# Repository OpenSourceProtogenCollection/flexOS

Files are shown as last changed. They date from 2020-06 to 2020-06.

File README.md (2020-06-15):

# flexOS
 The full files created for Subwuffer the Protogen, to help anyone create their own protogen fursuit
 
 Please check the wiki to get started.
 
#### GitHub Info
 
 
 
 
#### Contact
 
 
 
 
 
#### Code Status
 
 
 
 
 Waiting on shipment of new microcontrollers to update shell and Python with static USB binds.

# Quick Build Video

Watch the video here (https://youtu.be/kCo-e5A9jBQ)

# Requirements
## Hardware
- WS2812B boards (or other FastLED-compatible LED matrices)
	- I recommend 8x8 grids for cheeks and shoulders, 16x16 grids for legs, and 8x32 grids (x2) for visors
	- These can be found cheaply on AliExpress, but you can buy the more power-efficient versions from Adafruit
- Power sources
	- You'll need to do your own calculations as to how much power you'll need. I ended up going with 4 NiMH AA batteries, which gives 4.8V for every 4-battery holder
- Arduino (or other avr microcontrollers)
	- I went with Nanos, but these may be a bit limited in memory, so I'd recommend ESP32s. This one is up to you. Again, cheap ones can be found on AliExpress	
- Raspberry Pi
	- This one is only if you want to switch emotes in real-time. You will need wireless and the extra GPIO, so get either a 3B+ or newer, or a 1B+ or a 2B+ with a wireless adapter. I went with a 2B+ with a wireless adapter. Don't get a Pi A or Pi B, there aren't enough GPIO pins.
- Hall-effect sensors or reed switches (only for emote switching)
- 220 Ohm resistors, wires etc

## Software
- Codepad of your choice (VSCode and N++ are my choice for these languages)
- Arduino IDE
	- You must also have the following libraries installed:
		- [https://github.com/FastLED/FastLED](FastLED) for drawing arrays of LEDs (can and should be installed from Library Manager)
		- [https://github.com/AaronLiddiment/LEDText](LEDText) for scrolling text
		- [https://github.com/AaronLiddiment/LEDMatrix](LEDMatrix) for drawing shapes. I actually recommend using [jorgen-vikinggod's fork](https://jorgen-vikinggod.github.io/LEDMatrix/) for added functionality.
	- If you're coding and flashing on the go, ArduinoDroid works quite well
- [https://pixilart.com/draw](PixilArt) (web app)
- An image overlay program. For Windows there's OVERLAY2, but it's pretty persistent nagware. There's a better program out there by the name of Image Overlay Utility, but I'm not going to link it here due to (potentially false) positive malware alerts on it. If you go Googling for this, I reiterate that I'm not liable for any damage done. With that said, it seems to work fine on my machine, I have not seen any suspicious activity. If you would like me to screenshot you overlays of your pixel art, shoot me a [Telegram message](https://t.me/JaredTamana).
- A Linux-flashed SD card for your Raspberry Pi. I recommend Raspberry Pi OS. For more details on software for your installation, check the wiki.

# Notes
- I do not support macOS or Linux at this time. The reason I don't support macOS is because I don't own a macOS machine. However, the reason I don't support Linux is because the IDE SUCKS on Linux. There's no Library Manager, the Import Libraries tool is broken, your headers and libraries can't just be in the same folder as your sketch, the auto-format tool behaves strangely, shift-backspace is a nightmare... I could go on, but in short, just don't code Arduino on Linux. It hurts me to not support this because I love Linux and it sucks to have to switch between my Windows machine and my RPi constantly, but until Arduino fixes their IDE, I can't use it. If there's something specific that needs to be fixed for Linux or macOS compatibility let me know and I can look into fixing it.
- This is a WORK IN PROGRESS. I'm very much learning and working with this.
- These are Subwuffer's files in their entirety. You are welcome to use them as-is, but I highly encourage diving into the code and customizing things. I've made it very easy through code comments and the wiki to find your way around ^^
- I do not own the protogen species. For more info on the species and what can and cannot be used in your protogen, please visit [the creator's website](https://www.primaproto.com/). At the time of writing, this site is down for maintenance, but a [backup](https://web.archive.org/web/20191025141630/https://www.primaproto.com/) can be found on the Wayback Machine. For some reason this backup is SUPER slow, so the most relevant documentation has also been saved [in PDF format](https://drive.google.com/drive/folders/186GqGnEvYNcJsp2UskimsFtEwQ23Y9nJ?usp=sharing). (These are © MaliceRisu and therefore are not part of OSPC, they're only linked here for your convienence.)
- Big thanks to [Jting-F](https://www.youtube.com/channel/UCz8RfRGTDPPoexpyAg22kbg) for the inspiration and guidance along the way <3
- Like what I do? You can find a Sponsor button right beside the Watch, Star and Fork buttons. Any bit is really appreciated. I put a lot of time into this project because I saw a need for it and I enjoy it, but it's completely free for anyone to use.

# Getting in touch
I love to see what others make! If you have any questions or just want to chat about this project, you can click one of the badges above to get in touch with me. Please do try to contact me on Telegram first, that's where I'm most active.

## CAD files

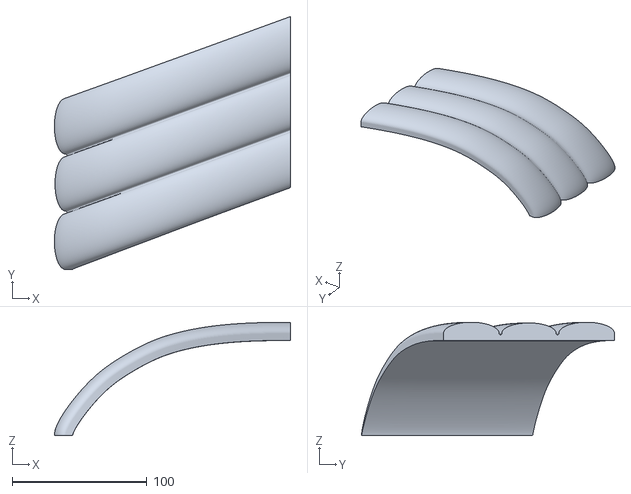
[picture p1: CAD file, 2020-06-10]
modeling/chest plate left completed_2.stl
175.4 x 187.8 x 84.2

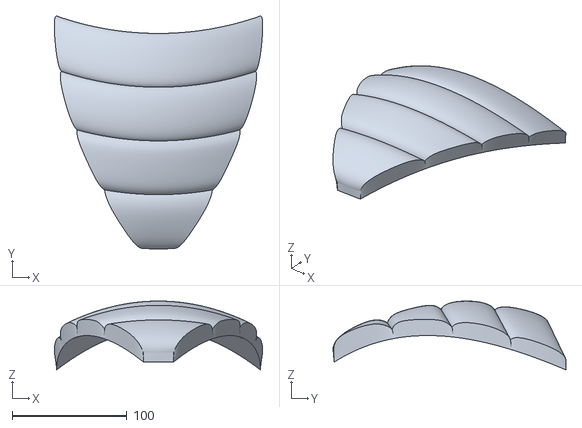
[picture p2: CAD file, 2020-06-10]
modeling/crotch plate completed_1.stl
181.9 x 203.3 x 60.1

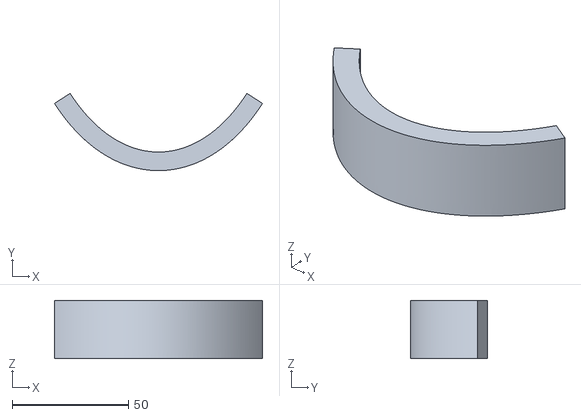
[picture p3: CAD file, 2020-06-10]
modeling/crotch plate connector completed_1.stl
89.5 x 33.2 x 25.0

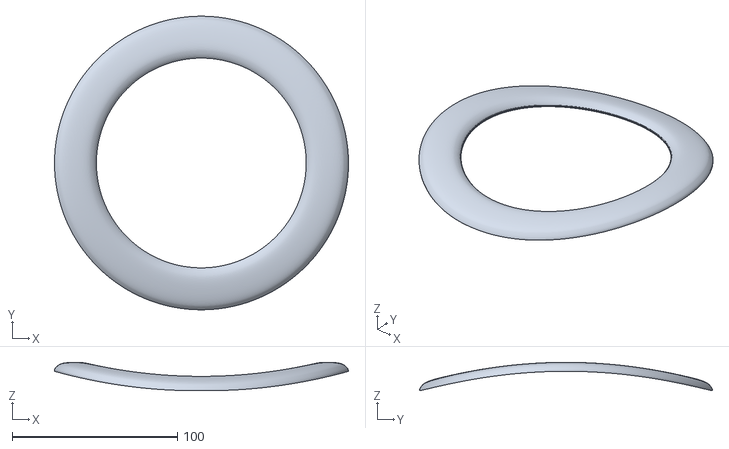
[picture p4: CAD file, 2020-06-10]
modeling/shoulder palte completed_2.stl
178.0 x 177.8 x 17.2

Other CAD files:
modeling/chest plate right completed_2.stl

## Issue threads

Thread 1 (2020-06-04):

ProtogenSSH: Buttons do not save to Internal Storage

JaredTheWolf, 2020-06-04:

JaredTheWolf, 2020-06-04:
I'm not sure how I want to implement this right now.

- I could use an SQLite database for it
- I could use a JSON (or other file) to store each button as its own Object

JaredTheWolf, 2020-06-04:
As of the latest commit (50ca525f391bec891c94252341ccfebedc6a58a6) read/write has been implemented but write don't seem to be working properly as read always reports the file as not found. Investigating.

JaredTheWolf, 2020-06-04:
Fixed by 5d37c59254449ff868785f9808e9db44832bd5c0

Closed 2020-06-04.

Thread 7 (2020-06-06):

ProtogenSSH: Passwords are not stored in encrypted SharedPrefs

JaredTheWolf, 2020-06-06:
Due to some issues with the crypto classes, passwords are currently stored alongside username and port info in regular SharedPrefs. This should probably be corrected. When I close this issue, I'll likely maintain a version of ProtogenSSH that does not use the crypto, as the current SDK I'm building for does not support it, but I want people to be able to use old phones they have knocking around if they choose to do so.

Closed 2020-06-07.

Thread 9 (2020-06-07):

Shell: Create a script with udev rules that statically binds USB devices

JaredTheWolf, 2020-06-07:
https://unix.stackexchange.com/questions/66901/how-to-bind-usb-device-under-a-static-name

JaredTheWolf, 2020-06-27:
I've received some ESP32s, so this will be worked on in the coming days.

JaredTheWolf, 2022-01-01:
This was never worked on due to incompatibilites between ESP32 and the FastLED library. I am reinvesting in this project and will attempt to debug these incompatibilities and report them to the library maintainers accordingly, however there is no guarantee that it will work (if it's a problem with me) or that the maintainers will help (if it's FastLED).

This issue technically does not need to be done with ESP32s, I can work it out with Arduino Nanos, but I'd like to sort out my MCs first due to the memory limitations we were seeing on 328 Nanos.

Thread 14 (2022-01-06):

[Arduino] 16x16 Incomplete

JaredTheWolf, 2022-01-06:
**Issue Location**
Arduino example sketch `arduino16x16.ino`

**Describe the issue**
- Out of date in-code docs on line 63
- No implementation of serial connection to Pi
- Needs further testing to ensure working pattern drawing (16x16 was never as well tested as 32x8)

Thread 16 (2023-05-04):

[FEAT] ESP Based Web Interface

GetLifty, 2023-05-04:
**Is your feature request related to a problem? Please describe.**
The current system for controlling which animation is occuring on the panel requires the user to SSH into a raspberry pi and use python scripts to send serial commands to the microcontroller. This requires a base technical knowledge and is unwieldy for less experienced users.

**Describe the solution you'd like**
A simpler and cheaper system could be implemented using a simple ESP based web server that takes user input and sends commands across a serial link. This could also allow for the implementation of effects such as voice control using an I2S mic at a lower cost than the Pi alternative. It would still have the benefit of acting as an AP but requires significantly less time to prepare as no bash scripts have to be run for setup.

**Describe alternatives you've considered**
A Pi Zero W based alternative could also achieve cost savings, but would still use more power and would not be as readily purchasable as ESP chips.

**Additional context**
I have begun working on an implementation of this in the time whilst I wait for other components to arrive and have succesfully gotten a working AP, webpage and serial output working. I would be happy to commit this code if this sounds like a feature that could be implemented :). See attached screenshots for my progress!
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

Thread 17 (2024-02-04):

Work with Raspberry Pi 3 Model B V1.2

Maxime66410, 2024-02-04:
Hello, Do you think it works with a Raspberry Pi 3 Model B V1.2 ?

https://fccid.io/2ABCB-RPI32

https://techinfodepot.shoutwiki.com/wiki/RPF_Raspberry_Pi_3_Model_B

https://fcc.report/FCC-ID/2ABCB-RPI32

https://www.amazon.fr/Raspberry-Pi-Carte-Mère-Model/dp/B01CD5VC92

Maxime66410, 2024-02-05:
Raspberry Pi 3 B+ -> [Extended 40-pin GPIO header](https://www.raspberrypi.com/products/raspberry-pi-3-model-b-plus/)
Raspberry Pi 3 Model B -> [Extended 40-pin GPIO header](https://www.raspberrypi.com/products/raspberry-pi-3-model-b/)

I think that should do it !

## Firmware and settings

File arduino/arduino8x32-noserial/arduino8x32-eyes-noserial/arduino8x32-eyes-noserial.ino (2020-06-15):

/*
    This file is part of flexOS and The Open Source Protogen Collection (OSPC).
    flexOS is free software under the MIT license. Please see https://opensource.org/licenses/MIT for more info
*/

/*                 _       _
     /\           | |     (_)
    /  \   _ __ __| |_   _ _ _ __ ______ _____      _____
   / /\ \ | '__/ _` | | | | | '_ \______/ _ \ \ /\ / / _ \
  / ____ \| | | (_| | |_| | | | | |    | (_) \ V  V / (_) |
 /_/    \_\_|  \__,_|\__,_|_|_| |_|     \___/ \_/\_/ \___/ */

#include "config.h" // this file includes our libraries and device-specific variables
#include "declarations.h" // this file includes variables for LED patterns

// creating the matrix using LEDMatrix
// note that height and width are flipped in this example due to TILE_TYPE
cLEDMatrix <MATRIX_TILE_HEIGHT, MATRIX_TILE_WIDTH, MATRIX_TILE_TYPE> ledmatrix;
// creating a pointer to the matrix so FastLED can still operate
CRGB *leds = ledmatrix[0];
// declaring LEDText
cLEDText ScrollingMsg;

// Purpose: Draws a single LED, then delays. Good for particle effects.
// Accepts: int index of LED, long int hex code, int time to delay after drawing (optional)
// Returns: Nothing
void singleLED(int number, long int colour, int delaytime = 0) {
  leds[number] = colour;
  if (delaytime > 0) {
    FastLED.show();
    FastLED.delay(delaytime);
  }
}

// Purpose: Draws LEDs by running through the pixels, one by one, and seeing if they should be lit up according to their array
// Accepts: uint16_t[] of your desired pattern, int size of the pattern array, long int hex code
// Returns: nothing
// For more details on how this works, see https://github.com/OpenSourceProtogenCollection/flexOS/wiki/Notes:-PROGMEM
void drawPattern(uint16_t patternArray[], int patternSize, long int colour) {
  // PGM comes into play here. For more info about PGM, see the declarations header or the wiki
  uint16_t nextPixel; // holds current RAM value from PGM
  int pixelCounter = 0; // increments when a pixel is placed
  for (int i = 0; i < NUM_LEDS; i++) { // loop through LED in the matrix
    for (int j = 0; j < patternSize; j++) { // check every element in the pattern array for the current LED
      nextPixel = pgm_read_word(&patternArray[pixelCounter]); // pull element into RAM
      if (i == nextPixel) { // if the pixel in the matrix matches the array element
        leds[i] = colour; // turn the pixel the specified colour
        pixelCounter++; // move to the next pixel
      }
    }
  }
}

// pattern-writing functions start here

void writeAttnEyes() {
  FastLED.clear();
  drawPattern(attentionEyes, ATTN_EYES, CRGB::Red);
  FastLED.show();
  FastLED.delay(500);
  FastLED.clear();
  FastLED.show();
  FastLED.delay(500);
}

void writeChgEyes() {
  FastLED.clear();
  drawPattern(chargeEyes, CHG_EYES, CRGB::Yellow);
  FastLED.show();
  FastLED.delay(500);
  for (int i = 0; i < 2; i++) {
    drawPattern(chargeEyesRemove, CHG_EYES_R, CRGB::Black);
    drawPattern(chargeEyesAdd, CHG_EYES_R, CRGB::Yellow);
    FastLED.show();
    FastLED.delay(500)
    FastLED.clear();
    drawPattern(chargeEyes, CHG_EYES, CRGB::Yellow);
    FastLED.show();
    FastLED.delay(500)
  }
    singleLED(12, CRGB::Yellow, 100);
    singleLED(62, CRGB::Yellow, 100);
    singleLED(88, CRGB::Yellow, 100);
    singleLED(161, CRGB::Yellow, 100);
    singleLED(234, CRGB::Yellow, 100);
    singleLED(167, CRGB::Yellow, 500);
    FastLED.clear();
}

void writeCoffeeEyes() {
    FastLED.clear();
    drawPattern(coffeeEyesBlue, COF_EYES_B, purpleblue);
    drawPattern(coffeeEyesWhite, COF_EYES_W, CRGB::White);
    FastLED.show(); FastLED.delay(750);
    drawPattern(coffeeEyesRemove, COF_EYES_R, CRGB::Black);
    drawPattern(coffeeEyesAdd, COF_EYES_R, CRGB::White);
    FastLED.show();
    FastLED.delay(500);
}

void writeDniEyes() {
    FastLED.clear();
    drawPattern(dniEyes, DNI_EYES, CRGB::Red);
    FastLED.show();
    FastLED.delay(1000);
    drawPattern(dniEyes, DNI_EYES, CRGB::White);
    FastLED.show();
    delay (1000);
}

void writeError() {
  while (true) {
    FastLED.clear();
    drawPattern(errSt, ERR_S, CRGB::Red);
    FastLED.show();
    FastLED.delay(1000);
    drawPattern(errR1, ERR_1, CRGB::Black);
    drawPattern(errA, ERR_1, CRGB::Red);
    FastLED.show();
    FastLED.delay(250);
    FastLED.clear();
    drawPattern(errSt, ERR_S, CRGB::Red);
    FastLED.show();
    FastLED.delay(250);
    drawPattern(errR1, ERR_1, CRGB::Black);
    drawPattern(errA, ERR_1, CRGB::Red);
    drawPattern(errAGn, ERR_2, seafoam);
    drawPattern(errAB, ERR_2, CRGB::Blue);
    FastLED.show();
    FastLED.delay(100);
    FastLED.clear();
    drawPattern(errSt, ERR_S, CRGB::Red);
    drawPattern(errAGn, ERR_2, seafoam);
    drawPattern(errAB, ERR_2, CRGB::Blue);
    drawPattern(errAY, ERR_Y, CRGB::Yellow);
    drawPattern(errAGr, ERR_3, bluegray);
    drawPattern(errAP, ERR_3, CRGB::Purple);
    FastLED.show();
    FastLED.delay(250);
    drawPattern(errR2, ERR_2, CRGB::Black);
    FastLED.show();
    FastLED.delay(250);
}

void writeCheckEyes() {
    FastLED.clear();
    drawPattern(checkEyes1, CHK_EYES_1, CRGB::Green);
    FastLED.show();
    FastLED.delay(250);
    drawPattern(checkEyes2, CHK_EYES_M, CRGB::Green);
    FastLED.show();
    FastLED.delay(250);
    drawPattern(checkEyes3, CHK_EYES_M, CRGB::Green);
    FastLED.show();
    FastLED.delay(250);
    drawPattern(checkEyes4, CHK_EYES_L, CRGB::Green);
    FastLED.show();
    FastLED.delay(1000);
}

void writeWrongEyes() {
    FastLED.clear();
    ledmatrix.DrawLine(13, 7, 20, 0, CRGB::Red);
    ledmatrix.DrawLine(13, 0, 15, 2, CRGB::Red);
    ledmatrix.DrawLine(20, 7, 18, 5, CRGB::Red);
    FastLED.show();
    FastLED.delay(150);
    FastLED.clear();
    FastLED.show();
    FastLED.delay(150);
    ledmatrix.DrawLine(13, 7, 20, 0, CRGB::Red);
    ledmatrix.DrawLine(13, 0, 15, 2, CRGB::Red);
    ledmatrix.DrawLine(20, 7, 18, 5, CRGB::Red);
    FastLED.show();
    FastLED.delay(150);
    FastLED.clear();
    FastLED.show();
    FastLED.delay(150);
    ledmatrix.DrawLine(13, 7, 20, 0, CRGB::Red);
    ledmatrix.DrawLine(13, 0, 15, 2, CRGB::Red);
    ledmatrix.DrawLine(20, 7, 18, 5, CRGB::Red);
    FastLED.show();
    FastLED.delay(1000);
}

void writeIdleEyes() {
    FastLED.clear();
    ledmatrix.DrawRectangle(3, 4, 4, 6, CRGB::White);
    ledmatrix.DrawRectangle(27, 4, 28, 6, CRGB::White);
    FastLED.show();
    FastLED.delay(3000);
    FastLED.clear();
    ledmatrix.DrawRectangle(3, 4, 4, 5, CRGB::White);
    ledmatrix.DrawRectangle(27, 4, 28, 5, CRGB::White);
    FastLED.show();
    delay(100);
    FastLED.clear();
    ledmatrix.DrawRectangle(3, 4, 4, 4, CRGB::White);
    ledmatrix.DrawRectangle(27, 4, 28, 4, CRGB::White);
    FastLED.show();
    delay(100);
    FastLED.clear();
    ledmatrix.DrawRectangle(3, 4, 4, 5, CRGB::White);
    ledmatrix.DrawRectangle(27, 4, 28, 5, CRGB::White);
    FastLED.show();
    delay(100);
}

void writeCryingEyes() {
  // this will probably just be shorter if I write it with int arrays
  while (true) {
    FastLED.clear();
    ledmatrix.DrawRectangle(3, 4, 4, 5, CRGB::White);
    ledmatrix.DrawRectangle(27, 4, 28, 5, CRGB::White);
    FastLED.show();
    FastLED.delay(1000);
    ledmatrix.DrawLine(3, 3, 4, 3, CRGB::Blue);
    ledmatrix.DrawLine(27, 3, 28, 3, CRGB::Blue);
    FastLED.show();
    delay(200);
    FastLED.clear();
    ledmatrix.DrawRectangle(3, 4, 4, 5, CRGB::White);
    ledmatrix.DrawRectangle(27, 4, 28, 5, CRGB::White);
    ledmatrix.DrawLine(3, 2, 4, 2, CRGB::Blue);
    ledmatrix.DrawLine(27, 2, 28, 2, CRGB::Blue);
    FastLED.show();
    delay(200);
    FastLED.clear();
    ledmatrix.DrawRectangle(3, 4, 4, 5, CRGB::White);
    ledmatrix.DrawRectangle(27, 4, 28, 5, CRGB::White);
    ledmatrix.DrawLine(3, 3, 4, 3, CRGB::Blue);
    ledmatrix.DrawLine(27, 3, 28, 3, CRGB::Blue);
    ledmatrix.DrawLine(3, 1, 4, 1, CRGB::Blue);
    ledmatrix.DrawLine(27, 1, 28, 1, CRGB::Blue);
    FastLED.show();
    delay(200);
    FastLED.clear();
    ledmatrix.DrawRectangle(3, 4, 4, 5, CRGB::White);
    ledmatrix.DrawRectangle(27, 4, 28, 5, CRGB::White);
    ledmatrix.DrawLine(3, 2, 4, 2, CRGB::Blue);
    ledmatrix.DrawLine(27, 2, 28, 2, CRGB::Blue);
    ledmatrix.DrawLine(3, 0, 4, 0, CRGB::Blue);
    ledmatrix.DrawLine(27, 0, 28, 0, CRGB::Blue);
    FastLED.show();
    delay(200);
    FastLED.clear();
    ledmatrix.DrawRectangle(3, 4, 4, 5, CRGB::White);
    ledmatrix.DrawRectangle(27, 4, 28, 5, CRGB::White);
    ledmatrix.DrawLine(3, 1, 4, 1, CRGB::Blue);
    ledmatrix.DrawLine(27, 1, 28, 1, CRGB::Blue);
    FastLED.show();
    delay(200);
    FastLED.clear();
    ledmatrix.DrawRectangle(3, 4, 4, 5, CRGB::White);
    ledmatrix.DrawRectangle(27, 4, 28, 5, CRGB::White);
    ledmatrix.DrawLine(3, 0, 4, 0, CRGB::Blue);
    ledmatrix.DrawLine(27, 0, 28, 0, CRGB::Blue);
    FastLED.show();
    delay(200);
  }
}

void writeIdEyes() {
  while (true) {
    FastLED.clear();
    ledmatrix.DrawRectangle(6, 0, 25, 7, CRGB::Blue);
    ledmatrix.DrawLine(19, 3, 15, 3, CRGB::Blue);
    ledmatrix.DrawLine(15, 5, 23, 5, CRGB::Blue);
    ledmatrix.DrawRectangle(9, 4, 10, 5, CRGB::Blue);
    ledmatrix.DrawRectangle(8, 1, 11, 2, CRGB::Blue);
    FastLED.show(); FastLED.delay(500);
    FastLED.clear();
    FastLED.show();
    FastLED.delay(750);
  }
}

void writeJoyEyes(bool laughing) {
  int eyeSpeed1;
  int eyeSpeed2;

  if (laughing) {
    eyeSpeed1 = 200;
    eyeSpeed2 = 150;
  }
  else {
    eyeSpeed1 = 1000;
    eyeSpeed2 = 1000;
  }
  
    FastLED.clear();
    ledmatrix.DrawLine(3, 4, 5, 6, 0xFFFFFF);
    ledmatrix.DrawLine(7, 4, 6, 5, 0xFFFFFF);
    ledmatrix.DrawLine(24, 4, 26, 6, 0xFFFFFF);
    ledmatrix.DrawLine(28, 4, 27, 5, 0xFFFFFF);
    FastLED.show();
    FastLED.delay(eyeSpeed1);
    FastLED.clear();
    ledmatrix.DrawLine(3, 5, 5, 7, 0xFFFFFF);
    ledmatrix.DrawLine(7, 5, 6, 6, 0xFFFFFF);
    ledmatrix.DrawLine(24, 5, 26, 7, 0xFFFFFF);
    ledmatrix.DrawLine(28, 5, 27, 6, 0xFFFFFF);
    FastLED.show();
    FastLED.delay(eyeSpeed2);
  }
}

void writePhoneEyes() {
    FastLED.clear();
    ledmatrix.DrawFilledRectangle(8, 1, 11, 3, CRGB::Blue);
    ledmatrix.DrawFilledRectangle(20, 1, 23, 3, CRGB::Blue);
    ledmatrix.DrawFilledRectangle(21, 3, 10, 5, CRGB::Blue);
    leds[180] = CRGB::Blue;
    leds[75] = CRGB::Blue;
    FastLED.show();
    delay(250);
    leds[51] = CRGB::Green;
    leds[52] = CRGB::Green;
    leds[58] = CRGB::Green;
    leds[70] = CRGB::Green;
    leds[73] = CRGB::Green;
    leds[182] = CRGB::Green;
    leds[185] = CRGB::Green;
    leds[197] = CRGB::Green;
    leds[203] = CRGB::Green;
    leds[204] = CRGB::Green;
    FastLED.show();
    delay(250);
    ledmatrix.DrawLine(26, 5, 26, 6, CRGB::Green);
    ledmatrix.DrawLine(25, 7, 24, 7, CRGB::Green);
    ledmatrix.DrawLine(6, 7, 7, 7, CRGB::Green);
    ledmatrix.DrawLine(5, 6, 5, 5, CRGB::Green);
    FastLED.show();
    delay(250);
  }
}

void writeSleepyEyes() {
  while (true) {
    FastLED.clear();
    ledmatrix.DrawLine(28, 5, 25, 5, CRGB::White);
    ledmatrix.DrawLine(6, 5, 3, 5, CRGB::White);
    FastLED.show();
    FastLED.delay(1000);
    FastLED.clear();
    drawPattern(zzzEyes1, ZZZ_EYES_S, CRGB::White);
    FastLED.show();
    FastLED.delay(300);
    drawPattern(zzzEyesA1, ZZZ_EYES_M, CRGB::White);
    drawPattern(zzzEyesR1, ZZZ_EYES_M, CRGB::Black);
    FastLED.show();
    FastLED.delay(300);
    FastLED.clear();
    drawPattern(zzzEyes1, ZZZ_EYES_S, CRGB::White);
    drawPattern(zzzEyesA2, ZZZ_EYES_M, CRGB::White);
    drawPattern(zzzEyesR2, ZZZ_EYES_M, CRGB::Black);
    FastLED.show();
    FastLED.delay(300);
    FastLED.clear();
    drawPattern(zzzEyes1, ZZZ_EYES_S, CRGB::White);
    drawPattern(zzzEyesA3, ZZZ_EYES_M, CRGB::White);
    drawPattern(zzzEyesR3, ZZZ_EYES_M, CRGB::Black);
    FastLED.show();
    if (Serial.available() > 0)
      break;
    FastLED.delay(300);
    FastLED.clear();
    drawPattern(zzzEyes1, ZZZ_EYES_S, CRGB::White);
    FastLED.show();
    FastLED.delay(1000);
  }
}

void writeLoadingEyes() {
  /* loading eyes - currently broken due to RAM usage */
    FastLED.clear();
    singleLED(151, rainbow[0]);
    singleLED(150, rainbow[1]);
    singleLED(149, rainbow[2]);
    singleLED(148, rainbow[3]);
    singleLED(147, rainbow[4]);
    singleLED(146, rainbow[5]);
    singleLED(145, rainbow[6]);

    // horrid manual method of doing things
    //    ledmatrix.ShiftUp();
    //    singleLED(topRow[0], rainbow[0], 150);
    //    ledmatrix.ShiftUp();
    //    singleLED(topRow[1], rainbow[0]);
    //    singleLED(topRow[0], rainbow[1], 150);
    //    ledmatrix.ShiftUp();
    //    singleLED(topRow[2], rainbow[0]);
    //    singleLED(topRow[1], rainbow[1]);
    //    singleLED(topRow[0], rainbow[2], 150);
    //    ledmatrix.ShiftUp();
    //    singleLED(topRow[3], rainbow[0]);
    //    singleLED(topRow[2], rainbow[1]);
    //    singleLED(topRow[1], rainbow[2]);
    //    singleLED(topRow[0], rainbow[3], 150);
    //    ledmatrix.ShiftUp();
    //    singleLED(topRow[4], rainbow[0]);
    //    singleLED(topRow[3], rainbow[1]);
    //    singleLED(topRow[2], rainbow[2]);
    //    singleLED(topRow[1], rainbow[3]);
    //    singleLED(topRow[0], rainbow[4], 150);
    //    ledmatrix.ShiftUp();
    //    singleLED(topRow[5], rainbow[0]);
    //    singleLED(topRow[4], rainbow[1]);
    //    singleLED(topRow[3], rainbow[2]);
    //    singleLED(topRow[2], rainbow[3]);
    //    singleLED(topRow[1], rainbow[4]);
    //    singleLED(topRow[0], rainbow[5], 150);
    //    ledmatrix.ShiftUp();
    //    singleLED(topRow[6], rainbow[0]);
    //    singleLED(topRow[5], rainbow[1]);
    //    singleLED(topRow[4], rainbow[2]);
    //    singleLED(topRow[3], rainbow[3]);
    //    singleLED(topRow[2], rainbow[4]);
    //    singleLED(topRow[1], rainbow[5]);
    //    singleLED(topRow[0], rainbow[6], 500);
    //    ledmatrix.ShiftRight();
    //    FastLED.show();

    // this is functional, but ShiftLeft and ShiftRight stall due to a lack of RAM. I'll have to rewrite it for manual shifting.
    for (int i = 0; i < 26; i++) {
      for (int j = 0; j <= i; j++) {
        singleLED(sequence[i - j], rainbow[j]);
      }
      FastLED.show();
      FastLED.delay(1000);
  }
}

void writeLostHandlerEyes() {
    ledmatrix.DrawFilledRectangle(0, 0, 31, 7, CRGB::White);

    if (ScrollingMsg.UpdateText() == -1)
      ScrollingMsg.SetText((unsigned char *)handlerEyesText, sizeof(handlerEyesText) - 1);
    else
      FastLED.show();
    FastLED.delay(15);
  }
}

void writeLowBatteryEyes() {
  while (true) {
    FastLED.clear();
    ledmatrix.DrawRectangle(8, 0, 9, 6, CRGB::White);
    ledmatrix.DrawRectangle(10, 0, 11, 2, CRGB::White);
    ledmatrix.DrawRectangle(13, 0, 17, 6, CRGB::White);
    ledmatrix.DrawLine(14, 1, 14, 5, CRGB::White);
    ledmatrix.DrawLine(19, 6, 19, 2, CRGB::White);
    ledmatrix.DrawLine(20, 0, 20, 1, CRGB::White);
    ledmatrix.DrawLine(21, 2, 21, 3, CRGB::White);
    ledmatrix.DrawLine(22, 0, 22, 1, CRGB::White);
    ledmatrix.DrawLine(23, 6, 23, 2, CRGB::White);
    FastLED.show();
    FastLED.delay(1000);
    FastLED.clear();
    drawPattern(chargeMouthOutline, CHG_MOUTH_O, CRGB::White);
    FastLED.show();
    FastLED.delay(1000);
  }
}

void writeOwoEyes() {
  FastLED.clear();
  ledmatrix.DrawRectangle(3, 4, 5, 6, CRGB::White);
  ledmatrix.DrawRectangle(26, 4, 28, 6, CRGB::White);
  FastLED.show();
}

void writeOwoMouth() {
  FastLED.clear();
  ledmatrix.DrawLine(10, 4, 13, 1, CRGB::White);
  ledmatrix.DrawLine(13, 1, 15, 3, CRGB::White);
  ledmatrix.DrawLine(16, 3, 18, 1, CRGB::White);
  ledmatrix.DrawLine(18, 1, 21, 4, CRGB::White);
  FastLED.show();
}

void writeUwuEyes() {
  FastLED.clear();
  ledmatrix.DrawRectangle(3, 4, 5, 6, CRGB::White);
  leds[217] = CRGB::Black;
  ledmatrix.DrawRectangle(26, 4, 28, 6, CRGB::White);
  leds[38] = CRGB::Black;
  FastLED.show();
}

void writeHeartEyes() {
    FastLED.clear();
    drawPattern(heartEyes, HRT_EYES, CRGB::Red);
    FastLED.show();
    FastLED.delay(500);
    ledmatrix.ShiftUp();
    FastLED.show();
    FastLED.delay(500);
}

void writeHungryEyes() {
  FastLED.clear();
  ledmatrix.DrawLine(14, 7, 17, 7, orangebrown);
  ledmatrix.DrawLine(13, 6, 18, 6, orangebrown);
  ledmatrix.DrawLine(12, 5, 19, 5, orangebrown);
  ledmatrix.DrawLine(12, 4, 19, 4, CRGB::Red);
  ledmatrix.DrawLine(12, 3, 19, 3, darkbrown);
  ledmatrix.DrawLine(12, 2, 19, 2, CRGB::Green);
  ledmatrix.DrawLine(12, 1, 19, 1, orangebrown);
  ledmatrix.DrawLine(13, 0, 18, 0, orangebrown);
  FastLED.show();
}

void writeInternalError() {
    FastLED.clear();
    if (ScrollingMsg.UpdateText() == -1) {
      ScrollingMsg.SetText(internalErrorText, 28);
      ScrollingMsg.SetTextColrOptions(COLR_RGB | COLR_SINGLE, 0xFF, 0x00, 0x00);
    } else {
      FastLED.show();
      FastLED.delay(20);
    }
}

void setup() {

  // instantiate FastLED
  FastLED.addLeds<MATRIX_BOARD_CHIP, LED_PIN, COLOR_ORDER>(ledmatrix[0], ledmatrix.Size());
  FastLED.setBrightness(BRIGHTNESS);
  Serial.begin(9600);

  // instantiate LEDText
  ScrollingMsg.SetFont(MatriseFontData);
  ScrollingMsg.Init(&ledmatrix, ledmatrix.Width(), ScrollingMsg.FontHeight() + 1, 0, 0);

  // make sure the matrix is clear before we go any further
  FastLED.clear();
  FastLED.show();
}

void loop() {
 // place the emotes you want to loop here
}

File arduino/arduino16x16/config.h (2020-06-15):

/*     
    This file is part of flexOS and The Open Source Protogen Collection (OSPC).
    flexOS is free software under the MIT license. Please see https://opensource.org/licenses/MIT for more info
*/


#ifndef config_h
#define config_h
#include <FastLED.h>
#include <LEDMatrix.h>

#define MATRIX_TILE_WIDTH   16 // width of matrix (not total display)
#define MATRIX_TILE_HEIGHT  -16 // height of matrix (negative due to flipped text, can use abs() to get positive)
#define MATRIX_TILE_TYPE VERTICAL_ZIGZAG_MATRIX
#define MATRIX_BOARD_CHIP WS2812B
#define MATRIX_TILE_H       1  // number of matrices arranged horizontally
#define MATRIX_TILE_V       1  // number of matrices arranged vertically
#define COLOR_ORDER GRB // hardware-dependent
#define LED_PIN 6 // pin where matrices are connected
#define NUM_LEDS abs(MATRIX_TILE_WIDTH) * abs(MATRIX_TILE_HEIGHT)

#define BRIGHTNESS 10 // brightness of LEDs
#endif

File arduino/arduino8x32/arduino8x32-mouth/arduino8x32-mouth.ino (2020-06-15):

/*
    This file is part of flexOS and The Open Source Protogen Collection (OSPC).
    flexOS is free software under the MIT license. Please see https://opensource.org/licenses/MIT for more info
*/

/*                 _       _
     /\           | |     (_)
    /  \   _ __ __| |_   _ _ _ __ ______ _____      _____
   / /\ \ | '__/ _` | | | | | '_ \______/ _ \ \ /\ / / _ \
  / ____ \| | | (_| | |_| | | | | |    | (_) \ V  V / (_) |
 /_/    \_\_|  \__,_|\__,_|_|_| |_|     \___/ \_/\_/ \___/ */

#include "config.h" // this file includes our libraries and device-specific variables
#include "declarations.h" // this file includes variables for LED patterns

// creating the matrix using LEDMatrix
// note that height and width are flipped in this example due to TILE_TYPE
cLEDMatrix <MATRIX_TILE_HEIGHT, MATRIX_TILE_WIDTH, MATRIX_TILE_TYPE> ledmatrix;
// creating a pointer to the matrix so FastLED can still operate
CRGB *leds = ledmatrix[0];
// declaring LEDText
cLEDText ScrollingMsg;

// Purpose: Draws a single LED, then delays. Good for particle effects.
// Accepts: int index of LED, long int hex code, int time to delay after drawing (optional)
// Returns: Nothing
void singleLED(int number, long int colour, int delaytime = 0) {
  leds[number] = colour;
  if (delaytime > 0) {
    FastLED.show();
    FastLED.delay(delaytime);
  }
}

// Purpose: Draws LEDs by running through the pixels, one by one, and seeing if they should be lit up according to their array
// Accepts: uint16_t[] of your desired pattern, int size of the pattern array, long int hex code
// Returns: nothing
// For more details on how this works, see https://github.com/OpenSourceProtogenCollection/flexOS/wiki/Notes:-PROGMEM
void drawPattern(uint16_t patternArray[], int patternSize, long int colour) {
  // PGM comes into play here. For more info about PGM, see the declarations header or the wiki
  uint16_t nextPixel; // holds current RAM value from PGM
  int pixelCounter = 0; // increments when a pixel is placed
  for (int i = 0; i < NUM_LEDS; i++) { // loop through LED in the matrix
    for (int j = 0; j < patternSize; j++) { // check every element in the pattern array for the current LED
      nextPixel = pgm_read_word(&patternArray[pixelCounter]); // pull element into RAM
      if (i == nextPixel) { // if the pixel in the matrix matches the array element
        leds[i] = colour; // turn the pixel the specified colour
        pixelCounter++; // move to the next pixel
      }
    }
  }
}

void writeAttnMouth() {
  /* attention mouth - this takes up a lot of space, consider replacing it with LEDText. https://github.com/AaronLiddiment/LEDText/issues/7 */
  while (true) {
    FastLED.clear();
    drawPattern(attentionMouth, ATTN_MOUTH, CRGB::Red);
    FastLED.show();
    FastLED.delay(500);
    FastLED.clear();
    FastLED.show();
    FastLED.delay(500);
    if (Serial.available() > 0)
      break;
  }
}

void writeChgMouth() {
  while (true) {
    FastLED.clear();
    drawPattern(chargeMouthOutline, CHG_MOUTH_O, CRGB::White);
    FastLED.show();
    FastLED.delay(750);
    drawPattern(chargeMouthBar1, CHG_MOUTH_B, CRGB::Green);
    FastLED.show();
    FastLED.delay(200);
    drawPattern(chargeMouthBar15, CHG_MOUTH_B, CRGB::Green);
    FastLED.show();
    FastLED.delay(200);
    drawPattern(chargeMouthBar2, CHG_MOUTH_B, CRGB::Green);
    FastLED.show();
    FastLED.delay(200);
    drawPattern(chargeMouthBar25, CHG_MOUTH_B, CRGB::Green);
    FastLED.show();
    FastLED.delay(200);
    drawPattern(chargeMouthBar3, CHG_MOUTH_B, CRGB::Green);
    FastLED.show();
    FastLED.delay(200);
    drawPattern(chargeMouthBar35, CHG_MOUTH_B, CRGB::Green);
    FastLED.show();
    FastLED.delay(200);
    drawPattern(chargeMouthBar4, CHG_MOUTH_B, CRGB::Green);
    FastLED.show();
    FastLED.delay(200);
    drawPattern(chargeMouthBar45, CHG_MOUTH_B, CRGB::Green);
    FastLED.show();
    FastLED.delay(750);
    FastLED.clear();
    if (Serial.available() > 0)
      break;
  }
}

void writeLostHandlerMouth() {
  while (true) {
    ledmatrix.DrawFilledRectangle(0, 0, 31, 7, CRGB::White);

    if (ScrollingMsg.UpdateText() == -1)
      ScrollingMsg.SetText((unsigned char *)handlerMouthText, sizeof(handlerMouthText) - 1);
    else
      FastLED.show();
    FastLED.delay(15);
    if (Serial.available() > 0)
      break;
  }
}

void writeLowBatteryMouth() {
  while (true) {
    FastLED.clear();
    drawPattern(lowBatMouth, LOW_MOUTH, CRGB::Yellow);
    FastLED.show();
    FastLED.delay(500);
    if (Serial.available() > 0)
      break;
    ledmatrix.DrawRectangle(13, 0, 15, 1, CRGB::Red);
    ledmatrix.DrawFilledRectangle(13, 3, 15, 7, CRGB::Red);
    ledmatrix.DrawRectangle(17, 0, 19, 1, CRGB::Red);
    ledmatrix.DrawFilledRectangle(17, 3, 19, 7, CRGB::Red);
    FastLED.show();
    FastLED.delay(500);
    if (Serial.available() > 0)
      break;
  }
}

void writeHappyMouth() {
  while (true) {
    FastLED.clear();
    ledmatrix.DrawLine(2, 6, 8, 1, CRGB::White);
    ledmatrix.DrawLine(8, 1, 10, 4, CRGB::White);
    ledmatrix.DrawLine(10, 4, 12, 1, CRGB::White);
    ledmatrix.DrawLine(12, 1, 15, 4, CRGB::White);
    ledmatrix.DrawLine(16, 4, 19, 1, CRGB::White);
    ledmatrix.DrawLine(19, 1, 21, 4, CRGB::White);
    ledmatrix.DrawLine(21, 4, 23, 1, CRGB::White);
    ledmatrix.DrawLine(29, 6, 23, 1, CRGB::White);
    FastLED.show();
    FastLED.delay(500);
    if (Serial.available() > 0)
      break;
    FastLED.delay(500);
    if (Serial.available() > 0)
      break;
    FastLED.delay(500);
    if (Serial.available() > 0)
      break;
    FastLED.delay(500);
    if (Serial.available() > 0)
      break;
    FastLED.delay(500);
    if (Serial.available() > 0)
      break;
    FastLED.delay(500);
    if (Serial.available() > 0)
      break;
    ledmatrix.DrawRectangle(15, 3, 16, 2, CRGB::White);
    FastLED.show();
    delay(50);
    ledmatrix.DrawFilledRectangle(14, 2, 17, 0, CRGB::White);
    leds[145] = CRGB::White;
    leds[110] = CRGB::White;
    ledmatrix.DrawLine(14, 0, 17, 0, CRGB::White);
    FastLED.show();
    delay(50);
    ledmatrix.DrawLine(11, 0, 20, 0, CRGB::White);
    leds[161] = CRGB::White;
    leds[94] = CRGB::White;
    FastLED.show();
    FastLED.delay(500);
    if (Serial.available() > 0)
      break;
    FastLED.delay(500);
    if (Serial.available() > 0)
      break;
    ledmatrix.DrawLine(11, 0, 13, 0, CRGB::Black);
    ledmatrix.DrawLine(18, 0, 20, 0, CRGB::Black);
    leds[161] = CRGB::Black;
    leds[94] = CRGB::Black;
    FastLED.show();
    delay(50);
    ledmatrix.DrawLine(13, 1, 18, 1, CRGB::Black);
    ledmatrix.DrawLine(13, 0, 18, 0, CRGB::Black);
    leds[141] = CRGB::Black;
    leds[114] = CRGB::Black;
    FastLED.show();
    delay(50);
    if (Serial.available() > 0)
      break;
  }
}
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

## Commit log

2020-05-24 Minor update to specify purpose of LEDMatrix
2020-05-25 Moved all LED writes into their own functions
    This commit prepares for Serial bridging to RasPi, so patterns can be called as needed. It also:
    - fixes some issues with singleLED, which now uses CRGB instead of LEDMatrix directly
    - merges the joy and laughing patterns into one function
    - adds the LostHandlerMouth and WIP Loading animations
2020-05-25 Initial commit of matrix design prototypes
2020-05-25 Add more pattern resources
    - arrays for loadingEyes
    - char array for handlerEyes
    - led int array for lowBatteryMouth
2020-05-25 Add info on jorgen-vikinggod's fork of LEDMatrix
2020-05-26 Rename .ino files to comply with Linux IDE
    For some reason, the Arduino IDE on Linux really doesn't like files being named with a number to start.
    [config.h]
2020-05-26 More renaming to make things work on Linux
    So I guess it also doesn't like dashes. Stellar work there, Arduino team, you really knocked it out of the park there.
    [arduino16x16.ino, arduino8x8.ino, config.h]
2020-05-27 Adding serial capability
    Not too long from now, `arduino8x32` will become `arduino8x32eyes`, and `arduino8x32mouth` will be created from what is left of the file
    [config.h]
2020-05-27 Move to characters for switch statement
    Saves on memory, etc
2020-05-27 Many changes to 32x8, see desc
    - Add separate files for mouth and eyes
    - Allow for serial reads to switch functions
    - Add writeBlank(), writeInternalError(), writeDniMouth()
    - Rename writeErrorEyes() to writeError() (and all affiliated vars)
    - Remove writeCoffeeMouth() due to RAM usage
    - Shorten dniText due to RAM limitations
    RAM is really close to full on the mouth matrix, I'll see what I can do to fix it qwq
    [arduino8x32-eyes.ino, arduino8x32-mouth.ino, config.h]
2020-05-28 Initial commit of LED strip files
2020-05-29 fix old call to writeErrorEyes
    [arduino8x32-eyes.ino]
2020-05-29 Rework and complete Python script with gpiozero
    gpiozero makes stuff much easier to work with :) This file is actually working now!!
    [main.py]
2020-05-30 Ignore sound files
    Unfortunately, the licenses attached to sound files mean I can't upload them here
2020-06-04 Add Android SSH client source
    [app_bar_main.xml]
2020-06-04 Bring in IO for buttons (incomplete)
2020-06-05 update material theme
2020-06-05 Switch EditTexts to Material TextInputLayout
2020-06-05 Fix theming issues (closes #6)
    [app_bar_main.xml]
2020-06-05 Swap toasts for snackbars in most places
    Snackbars currently don't theme dark, not sure if will fix
2020-06-05 Switch from JSch binary to Gradle build
2020-06-10 Add modeling files
    [chest plate left completed_2.stl, chest plate right completed_2.stl, crotch plate completed_1.stl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]
2020-06-10 Add asynchronous presses for buttons (closes #10)
    - Update version number
2020-06-15 Moving ProtogenSSH to new repo
    [app_bar_main.xml]
